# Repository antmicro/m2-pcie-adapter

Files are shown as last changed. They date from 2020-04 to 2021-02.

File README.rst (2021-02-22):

===========================
M.2 to PCIe x4 adapter card
===========================

Copyright (c) 2020-2021 Antmicro <`www.antmicro.com <https://www.antmicro.com>`_>

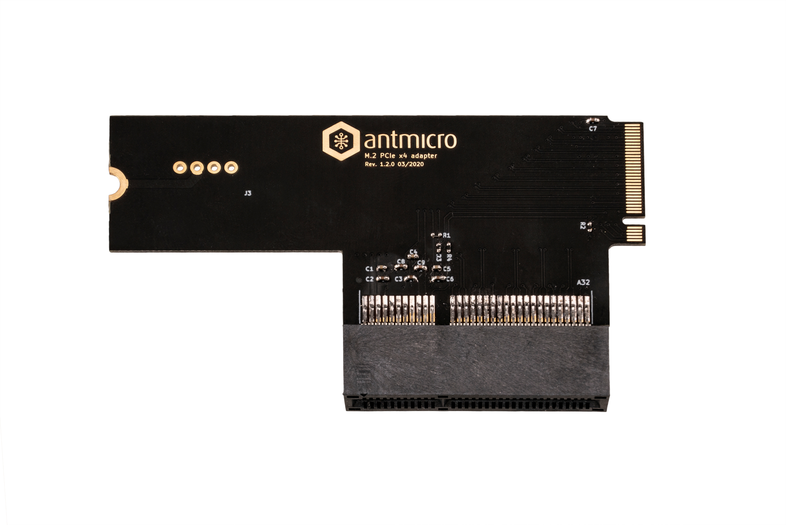
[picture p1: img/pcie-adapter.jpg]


Overview
========

This repository contains open hardware design files for an adapter card created to expose the Peripheral Component Interconnect Express (PCIe) signals available on the M.2 (key M) connector in a regular PCIe x4 edge card socket.
This board has been designed as an extension of the Antmicro's `Jetson Nano Baseboard <https://github.com/antmicro/jetson-nano-baseboard>`_.
It allows the use of regular PCIe expansion cards and accessories with the NVIDIA `Jetson Nano <https://www.nvidia.com/en-us/autonomous-machines/embedded-systems/jetson-nano/>`_ and NVIDIA `Jetson Xavier NX <https://www.nvidia.com/en-us/autonomous-machines/embedded-systems/jetson-xavier-nx/>`_ system on modules.

Key features
============

* M.2 (key-M) edge connector
* PCIe x4 EdgeMount connector (Samtec PCIE-064-02-F-D-EMS2)
* external power supply connector (Molex 22053041)
* Nano Baseboard power supply pogo pins (Harwin P70-1000045R)

The PCB project files were prepared in KiCAD.

Board layout & dimensions
=========================

The picture below presents the general layout and dimensions of the PCB.

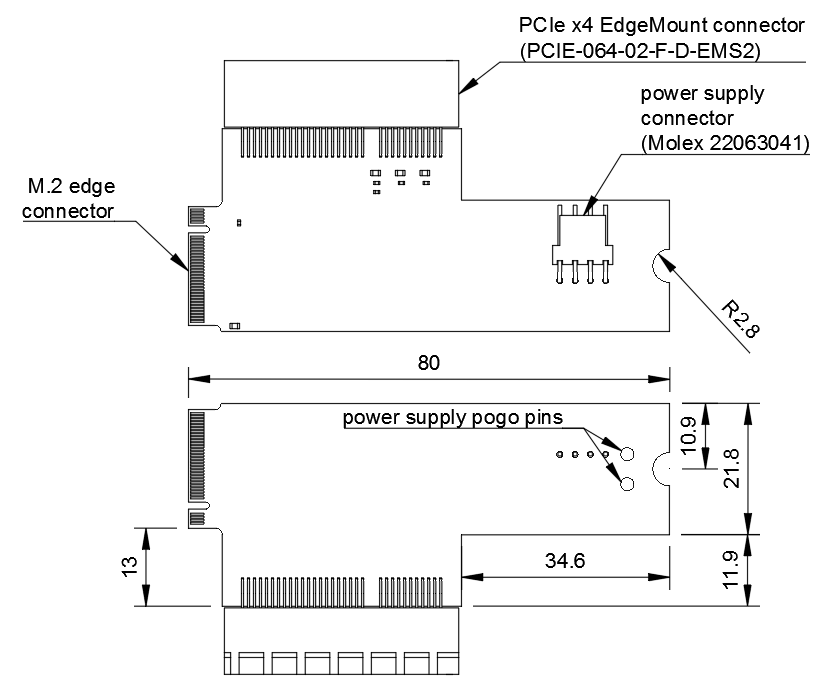
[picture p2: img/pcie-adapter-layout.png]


Getting started
===============

The PCB design does not include any active components.
It simply passes the signals from the M.2 connector to the PCIe card edge socket.
The final thickness of the PCB should be 0.8mm to make it fit in the M.2 slots.
Since most PCIe card edge connectors are adjusted for 1.55mm, some mechanical tooling is required to assemble the PCIe socket on the PCB.

License
=======

`Apache-2.0 <LICENSE>`_

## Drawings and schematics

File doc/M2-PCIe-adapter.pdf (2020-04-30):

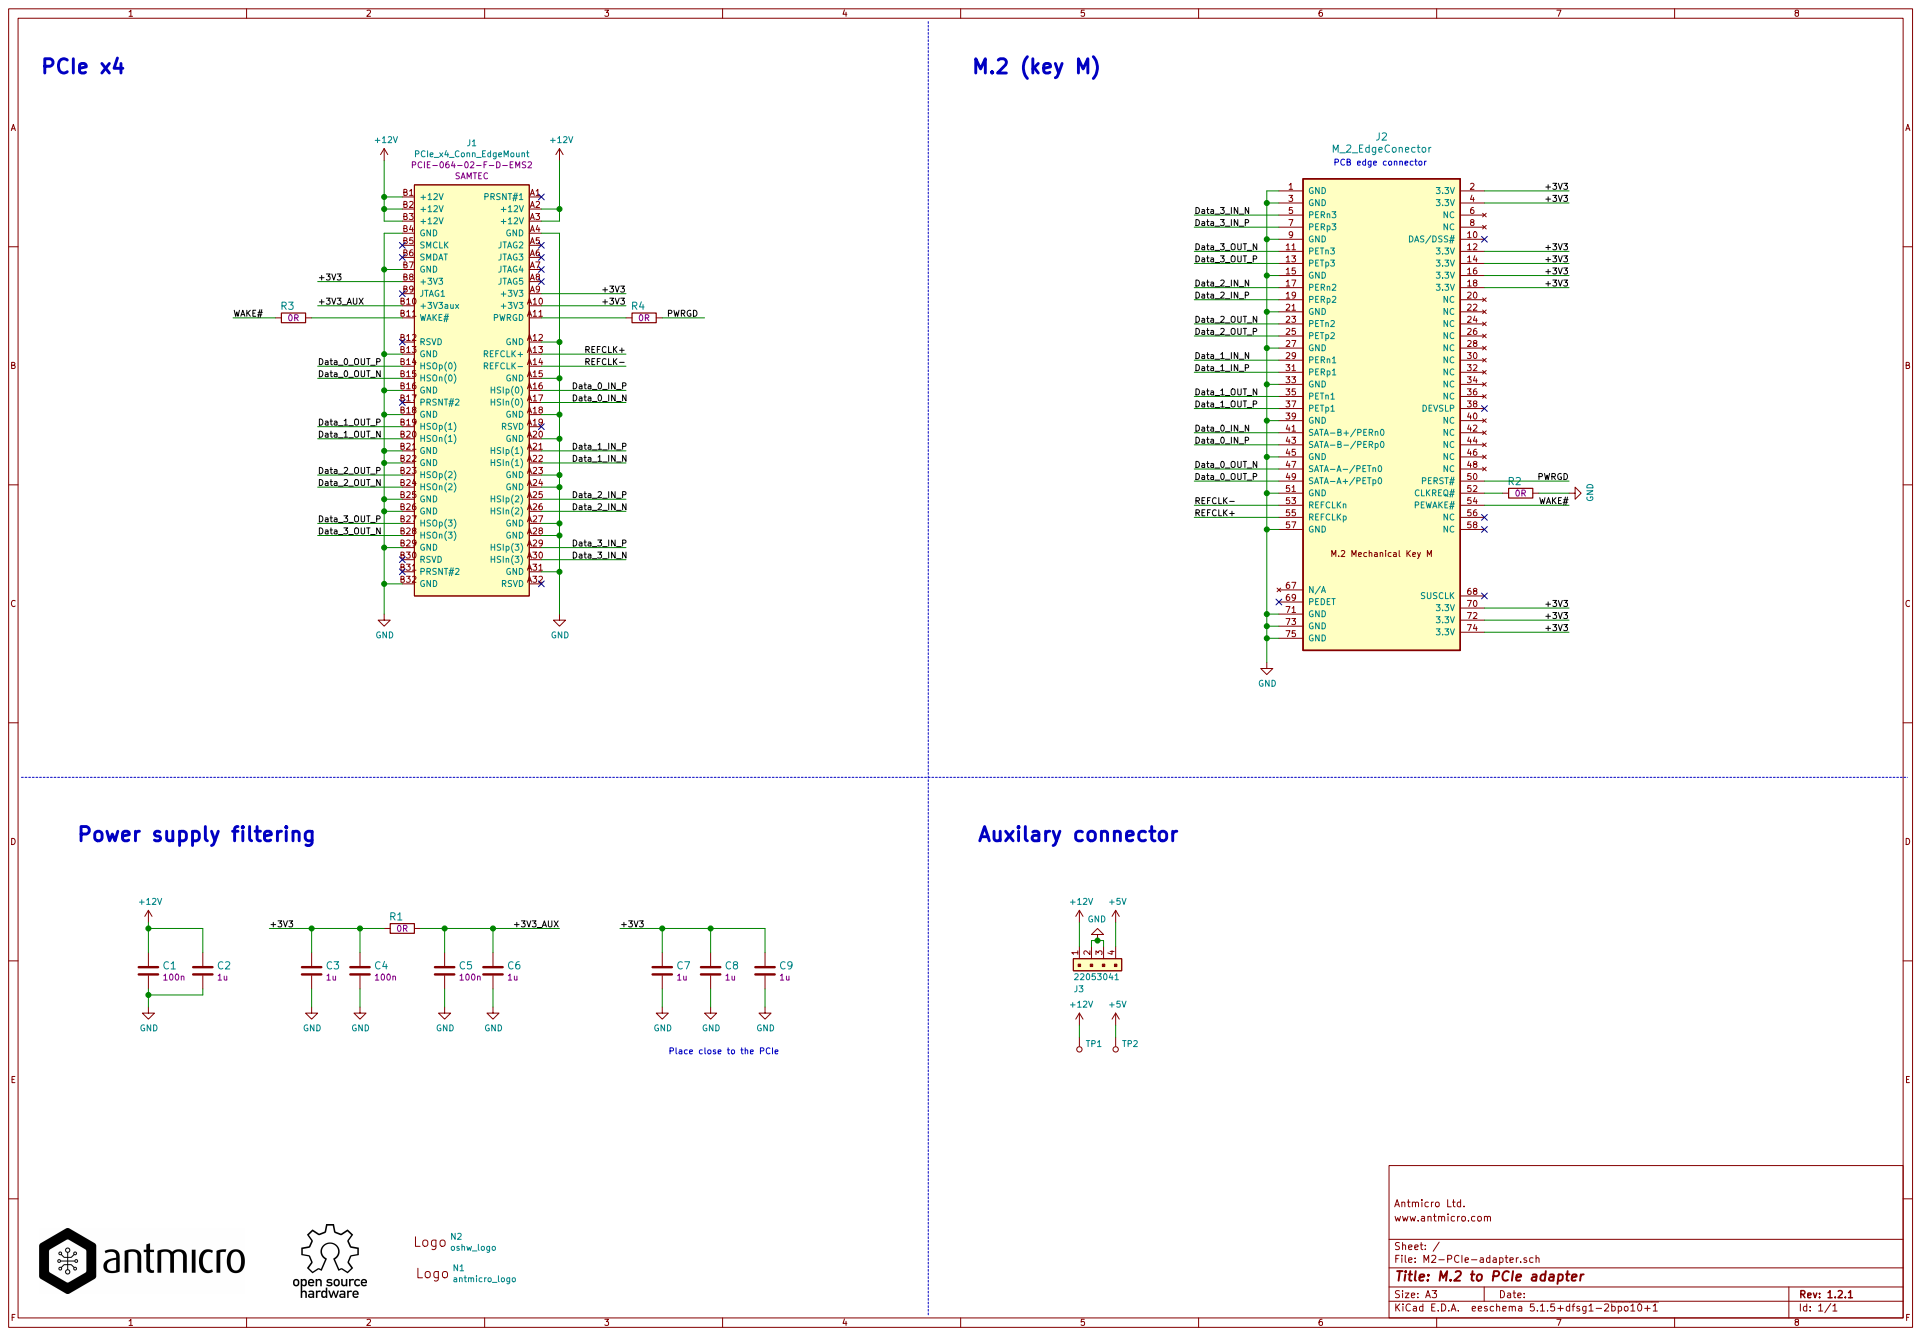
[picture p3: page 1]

REFCLK- REFCLK+ REFCLK- REFCLK+ Data_0_IN_N

Place close to the PCIe

File: M2-PCIe-adapter.sch Sheet: / www.antmicro.com

Id: 1/1 Title: M.2 to PCIe adapter

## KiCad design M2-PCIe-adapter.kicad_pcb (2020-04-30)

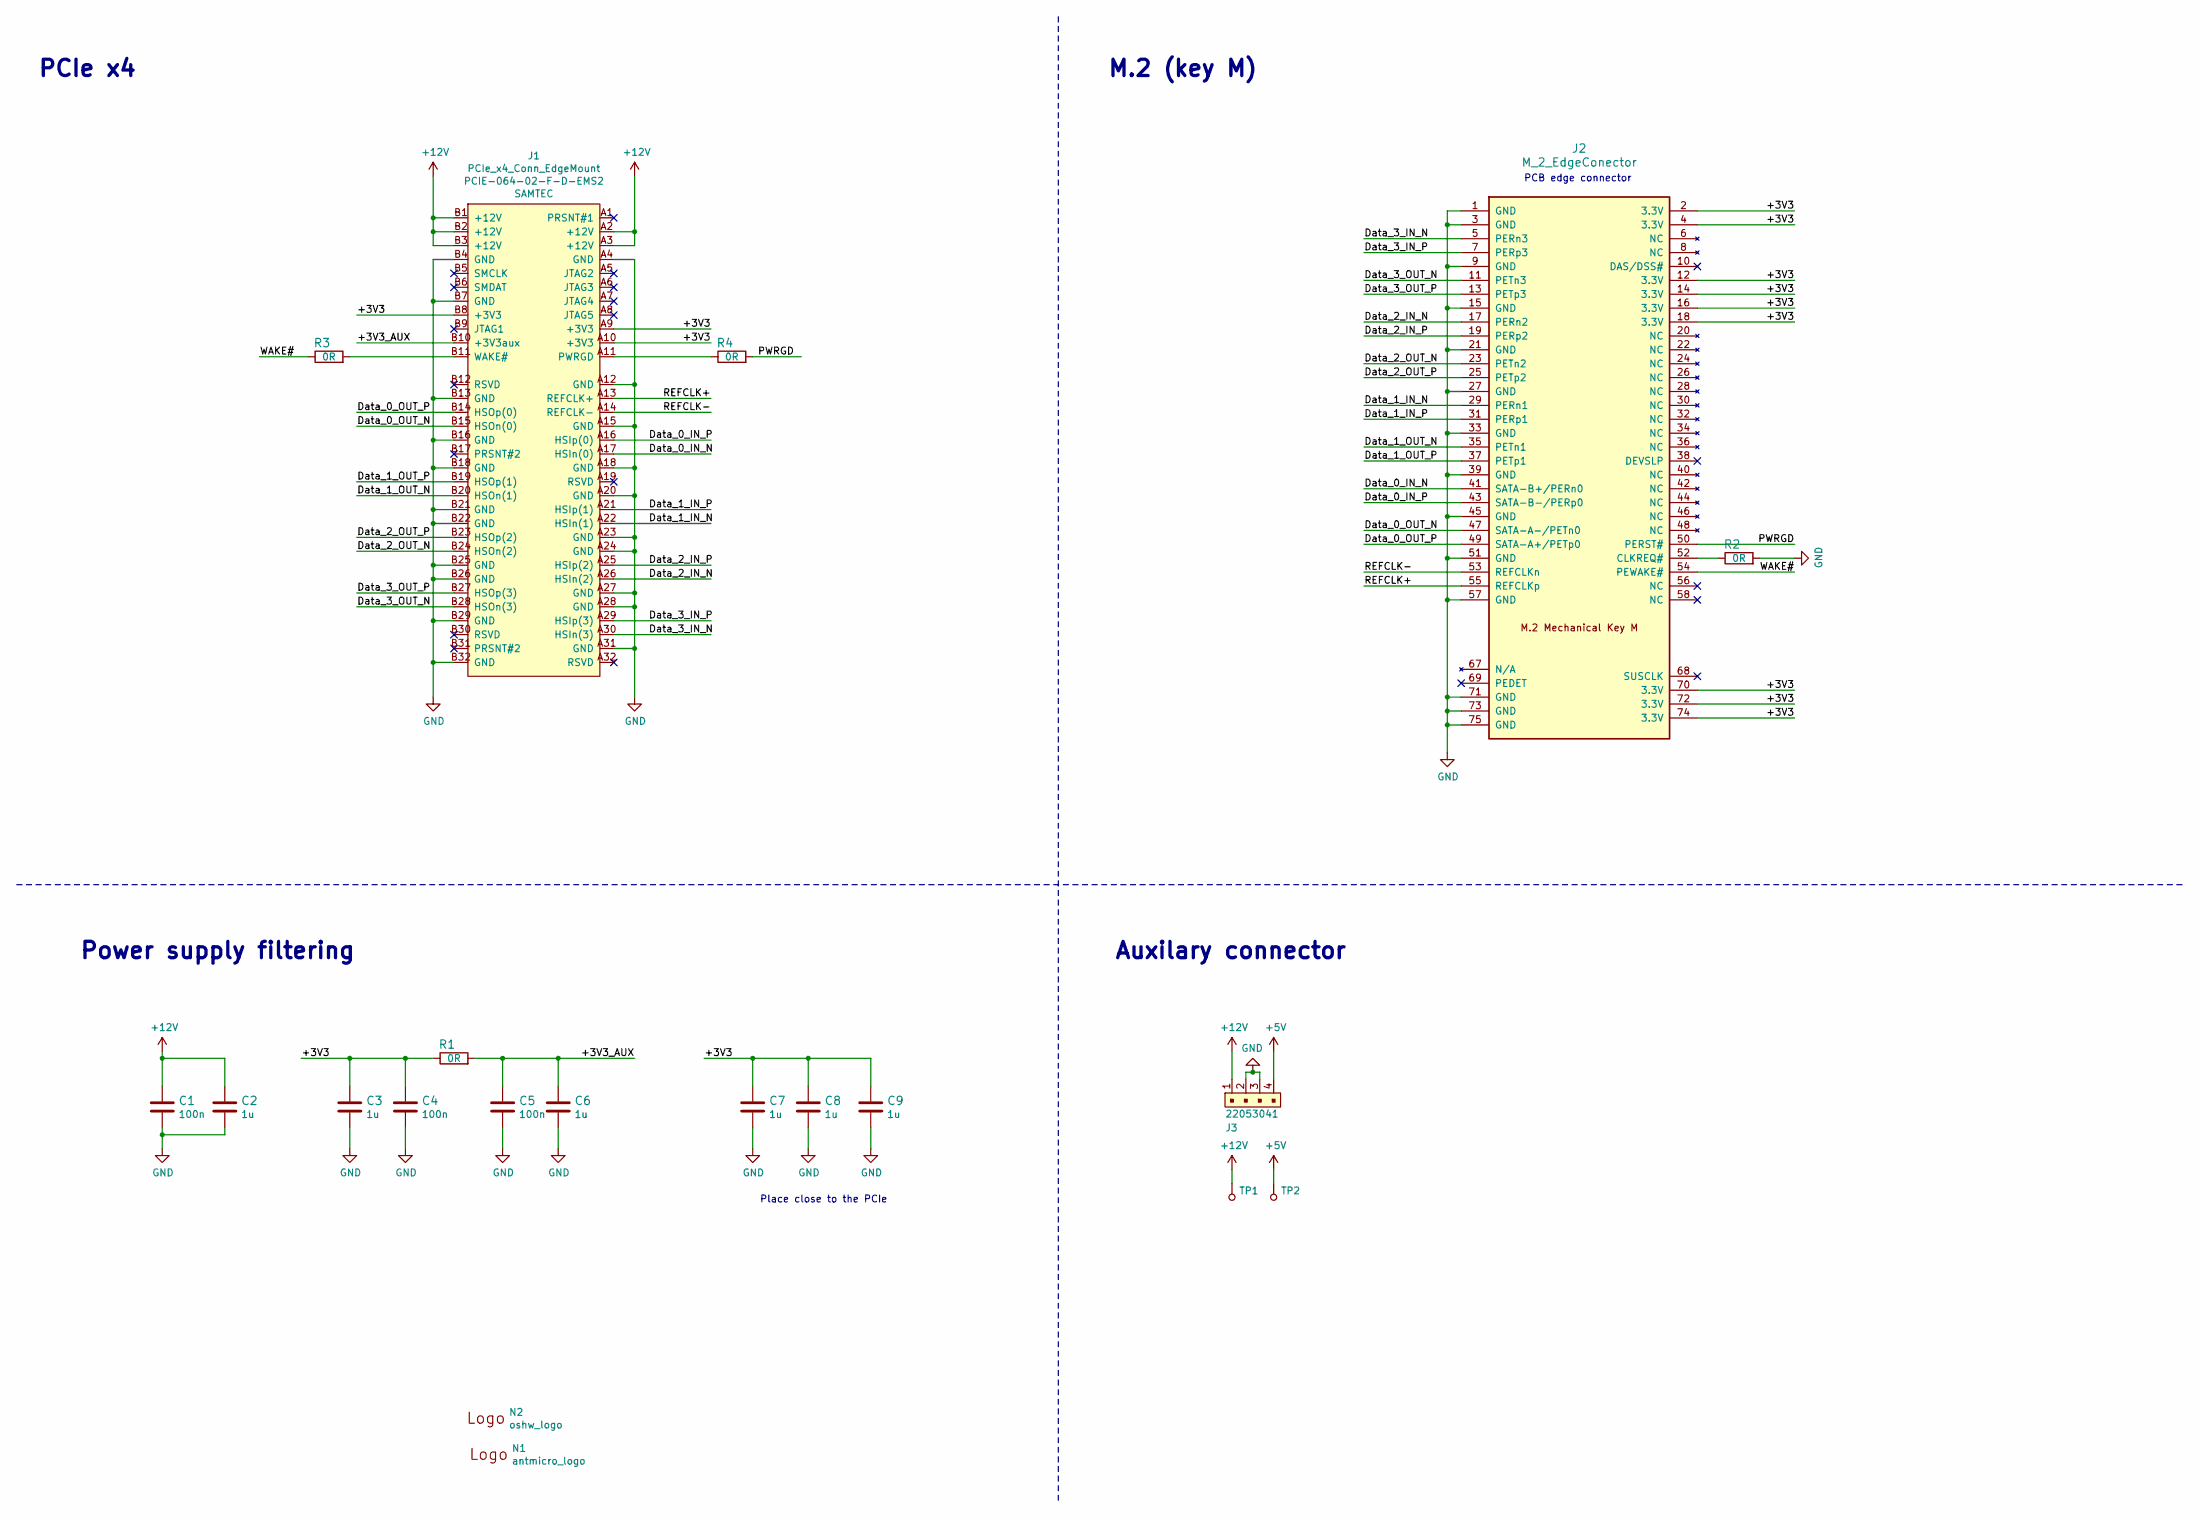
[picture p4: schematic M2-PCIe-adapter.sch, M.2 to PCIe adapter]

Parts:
C1, C4, C5: C_100n_0402_16V; 0402-cap; MPN MC0402B104K160CT
C2, C3, C6, C7, C8, C9: C_1u_0603; 0603-cap; MPN 0603X105K160CT
J1: PCIe_x4_Conn_EdgeMount; PCIE-064-02-X-D-EMSX; MPN PCIE-064-02-F-D-EMS2
J2: M_2_EdgeConector; M_2_EdgeConnector
J3: 22053041; MPN 22053041
N1: antmicro_logo; antmicro-logo_scaled_20mm
N2: oshw_logo; oshw-logo
R1, R2, R3, R4: R_0R_0402; 0402-res; MPN ERJ2GE0R00X
TP1, TP2: P70-1000045R; MPN P70-1000045R

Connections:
+5V: J3.4, TP2.1
+12V: C1.1, C2.1, J1.A2 (+12V), J1.A3 (+12V), J1.B1 (+12V), J1.B2 (+12V), J1.B3 (+12V), J3.1, TP1.1
/+3V3: C3.1, C4.1, C7.1, C8.1, C9.1, J1.A9 (+3V3), J1.A10 (+3V3), J1.B8 (+3V3), J2.2 (3.3V), J2.4 (3.3V), J2.12 (3.3V), J2.14 (3.3V), J2.16 (3.3V), J2.18 (3.3V), J2.70 (3.3V), J2.72 (3.3V), J2.74 (3.3V), R1.1
/+3V3_AUX: C5.1, C6.1, J1.B10 (+3V3aux), R1.2
/Data_0_IN_N: J1.A17 (HSIn(0)), J2.41 (SATA-B+/PERn0)
/Data_0_IN_P: J1.A16 (HSIp(0)), J2.43 (SATA-B-/PERp0)
/Data_0_OUT_N: J1.B15 (HSOn(0)), J2.47 (SATA-A-/PETn0)
/Data_0_OUT_P: J1.B14 (HSOp(0)), J2.49 (SATA-A+/PETp0)
/Data_1_IN_N: J1.A22 (HSIn(1)), J2.29 (PERn1)
/Data_1_IN_P: J1.A21 (HSIp(1)), J2.31 (PERp1)
/Data_1_OUT_N: J1.B20 (HSOn(1)), J2.35 (PETn1)
/Data_1_OUT_P: J1.B19 (HSOp(1)), J2.37 (PETp1)
/Data_2_IN_N: J1.A26 (HSIn(2)), J2.17 (PERn2)
/Data_2_IN_P: J1.A25 (HSIp(2)), J2.19 (PERp2)
/Data_2_OUT_N: J1.B24 (HSOn(2)), J2.23 (PETn2)
/Data_2_OUT_P: J1.B23 (HSOp(2)), J2.25 (PETp2)
/Data_3_IN_N: J1.A30 (HSIn(3)), J2.5 (PERn3)
/Data_3_IN_P: J1.A29 (HSIp(3)), J2.7 (PERp3)
/Data_3_OUT_N: J1.B28 (HSOn(3)), J2.11 (PETn3)
/Data_3_OUT_P: J1.B27 (HSOp(3)), J2.13 (PETp3)
/PWRGD: J2.50 (PERST#), R4.2
/REFCLK+: J1.A13 (REFCLK+), J2.55 (REFCLKp)
/REFCLK-: J1.A14 (REFCLK-), J2.53 (REFCLKn)
/WAKE#: J2.54 (PEWAKE#), R3.1
GND: C1.2, C2.2, C3.2, C4.2, C5.2, C6.2, C7.2, C8.2, C9.2, J1.A4 (GND), J1.A12 (GND), J1.A15 (GND), J1.A18 (GND), J1.A20 (GND), J1.A23 (GND), J1.A24 (GND), J1.A27 (GND), J1.A28 (GND), J1.A31 (GND), J1.B4 (GND), J1.B7 (GND), J1.B13 (GND), J1.B16 (GND), J1.B18 (GND), J1.B21 (GND), J1.B22 (GND), J1.B25 (GND), J1.B26 (GND), J1.B29 (GND), J1.B32 (GND), J2.1 (GND), J2.3 (GND), J2.9 (GND), J2.15 (GND), J2.21 (GND), J2.27 (GND), J2.33 (GND), J2.39 (GND), J2.45 (GND), J2.51 (GND), J2.57 (GND), J2.71 (GND), J2.73 (GND), J2.75 (GND), J3.2, J3.3, R2.2
unnamed: J1.A11 (PWRGD), R4.1
unnamed: J1.B11 (WAKE#), R3.2
unnamed: J2.52 (CLKREQ#), R2.1

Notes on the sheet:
Power supply filtering
Place close to the PCIe
PCIe x4
M.2 (key M)
PCB edge connector
Auxilary connector

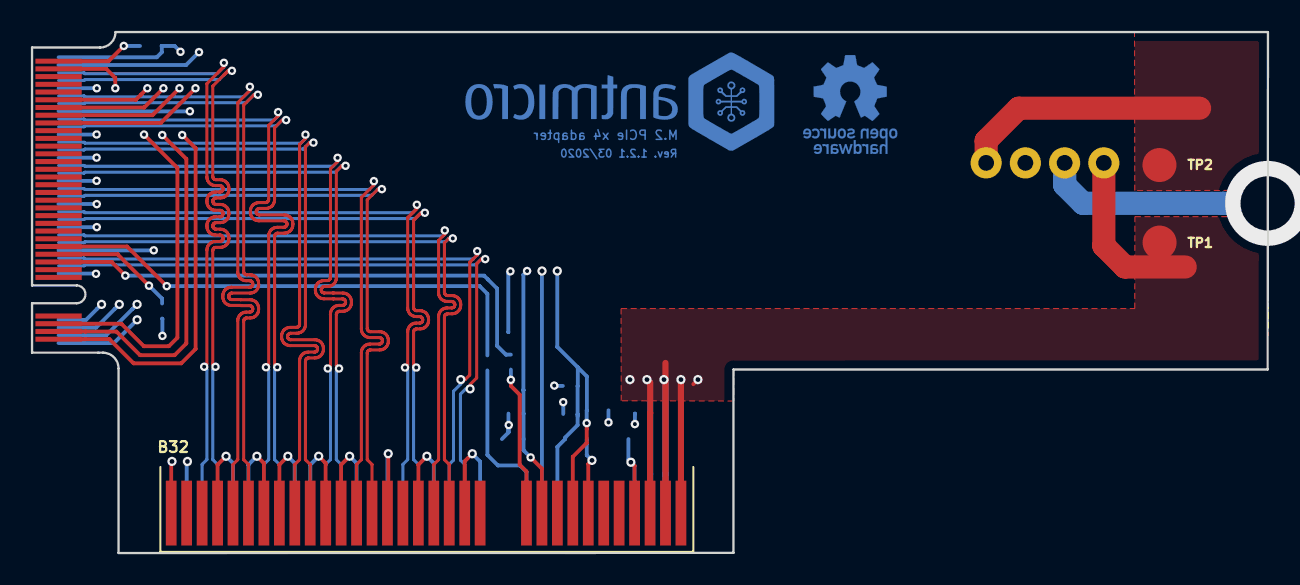
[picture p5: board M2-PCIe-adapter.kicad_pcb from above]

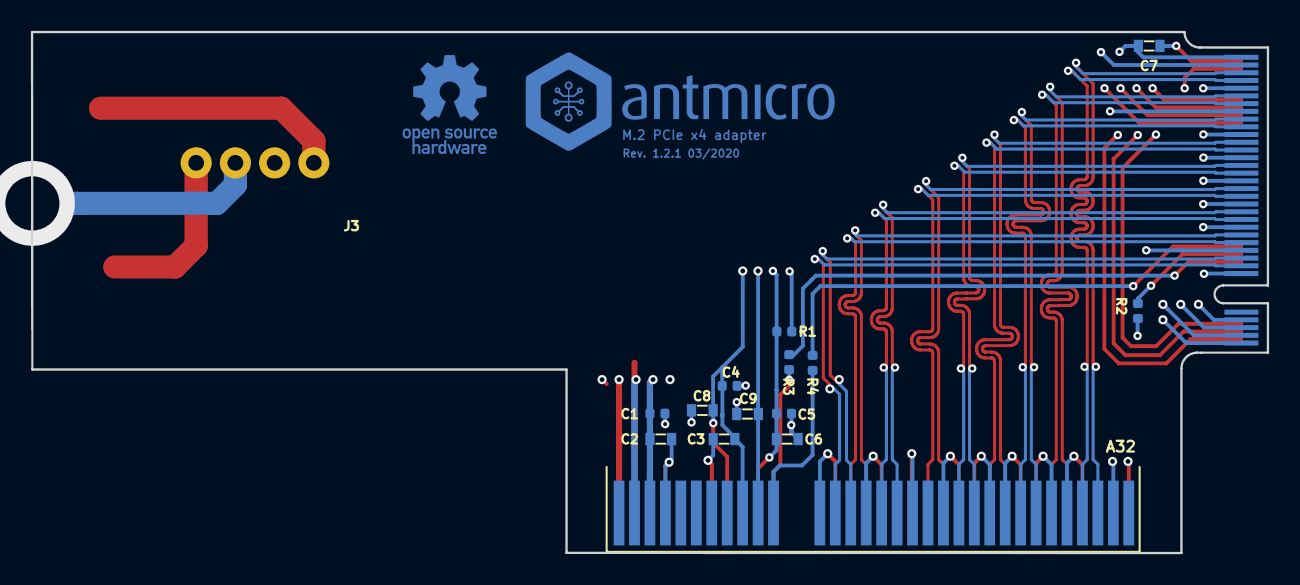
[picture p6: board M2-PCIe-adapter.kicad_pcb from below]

Board: 4 copper layers, 80.0 x 33.7 mm, 20 parts (16 on the bottom side), 28 nets.
